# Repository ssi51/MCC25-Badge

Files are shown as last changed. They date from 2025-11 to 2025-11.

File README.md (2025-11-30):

# MCC25 Badge

  

## 🦇 Introduction

Welcome to the official repository for the **MCC 25' Badge**, a custom electronic conference badge based on the open-source [Hackbat Badge](https://hackaday.io/project/197688-hackbat-badge).

**📡 Repository Updates & Future Code**
This repository is the central hub for the MCC 25' Badge ecosystem. **It will be regularly updated with new firmware, games, and example codes.** We encourage you to "Watch" or "Star" this repository to get notified when new features are available to upload to your badge.

## ✨ Features

* **Wireless Connectivity**: Integrated 2.4GHz WiFi and Bluetooth 5.0 (LE) via the ESP32-C3.
* **Crisp Display**: 1.3-inch OLED screen for menus, games, and status updates.
* **Interactive Controls**: 6-button interface (D-Pad + A/B buttons) designed for gaming and navigation.
* **RGB Lighting**: 4x Addressable WS2812 LEDs for visual notifications and light shows.
* **Portable Power**: Runs on USB-C or AA batteries with dedicated power management.
* **Open Development**: Compatible with Arduino IDE and Espressif ESP-IDF.

## 🛠 Hardware Specifications

| Component | Specification |
| :--- | :--- |
| **Microcontroller** | Espressif **ESP32-C3** (RISC-V Single-core @ 160MHz) |
| **Display** | 1.3" OLED (SH110x / SSD1306 compatible) |
| **Connectivity** | WiFi 802.11b/g/n + Bluetooth LE 5.0 |
| **User Input** | 6 Push Buttons (Up, Down, Left, Right, A, B) |
| **LEDs** | 4 x WS2812B Addressable RGB LEDs |
| **Dimensions** | 100mm x 60mm |
| **Power Input** | USB Micro or 3x AA Battery Holder (Back mounted) |

## 🚀 Getting Started

### Prerequisites

To program the MCC25 Badge, you will need to install the necessary drivers and boards.

1.  **Install Arduino IDE**: Download from the [official website](https://www.arduino.cc/en/software).
2.  **Add ESP32 Board Manager**:
    * Go to `File` > `Preferences`.
    * Add the following URL to "Additional Board Manager URLs":
        `https://raw.githubusercontent.com/espressif/arduino-esp32/gh-pages/package_esp32_index.json`
    * Go to `Tools` > `Board` > `Boards Manager`, search for "ESP32", and install.

### Flashing Your First Sketch

1.  Select the board: `ESP32C3 Dev Module`.
2.  Ensure `USB CDC On Boot` is set to "Enable" if you are using the USB port for serial debugging.
3.  Connect your MCC25 Badge via USB-Micro.
4.  Select the correct Port under `Tools` > `Port`.
5.  Upload the example `Blink` or `DisplayTest` sketch from the `/examples` folder in this repo.

## 🔋 Powering the Badge

The MCC25 Badge can be powered in two ways:
1.  **USB Mode**: Connect a USB Micro cable for power and programming.
2.  **Battery Mode**: Insert 3x AA batteries into the rear holder. Use the physical slide switch to toggle battery power ON/OFF.
    * *Note: Ensure batteries are removed if you are modifying hardware components.*

## 📂 Repository Structure

* `/examples` - Source code, future updates, and example sketches.
* `/hardware` - PCB design files (Gerbers, Schematics).
* `/docs` - Datasheets and additional documentation.

## 🤝 Credits & Acknowledgments

* **Original Design**: Based on the **Hackbat Badge** by [Pablo on Hackaday.io](https://hackaday.io/project/197688-hackbat-badge).
* **MCU**: Powered by Espressif Systems.

## 📄 License

This project is open-source.

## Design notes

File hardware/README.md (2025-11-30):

# 🛠️ MCC25 Badge Hardware Design

This directory contains the Open Source Hardware (OSHW) design files for the **MCC25 Badge**. The PCB was designed using **KiCad** (Version 7.0+).

## 📂 File Descriptions

| File Name | Description |
| :--- | :--- |
| `mcc25_badge.kicad_pro` | Main KiCad Project file. Open this to start editing. |
| `mcc25_badge.kicad_sch` | **Schematic**: Shows how the ESP32-C3 connects to the OLED, LEDs, and buttons. |
| `mcc25_badge.kicad_pcb` | **PCB Layout**: The physical board routing, layers, and footprints. |
| `gerber.zip` | **Production Files**: The exact manufacturing files needed to order this board from a fab house. |

## 📐 Technical Specifications
* **Layers:** 2-Layer PCB
* **Dimensions:** 100mm x 60mm
* **Thickness:** 1.6mm (Standard)
* **Signal Voltage:** 3.3V Logic

## 🏭 How to Order This Board (Fabrication)

You don't need to install KiCad if you just want to manufacture the PCB.

1.  **Download the Gerbers**: Download the file `gerber.zip` from this folder.
2.  **Visit a Manufacturer**: Go to a PCB fabrication website (e.g., JLCPCB, PCBWay, AiPCBA).
3.  **Upload**: Drag and drop the `gerber.zip` file into their "Quote" tool.
4.  **Select Settings**: The defaults are usually fine, but ensure the following:
    * **Layers**: 2
    * **Thickness**: 1.6mm
    * **PCB Color**: Black (Matches the MCC aesthetic)
    * **Surface Finish**: HASL (Cheaper) or ENIG (Better for gold pads)
5.  **Order**: Add to cart and ship!

## ✏️ How to Modify the Design

If you want to change the logo, move buttons, or add sensors:

1.  Install **KiCad** (Free & Open Source) from [kicad.org](https://www.kicad.org/).
2.  Clone this repository to your computer.
3.  Double-click `mcc25_badge.kicad_pro` to open the project manager.
4.  Open the **Schematic Editor** to change connections or the **PCB Editor** to change the physical layout.

## ⚠️ Assembly Note
This board uses **SMD (Surface Mount Device)** components for the ESP32-C3 and LEDs.
* If ordering **PCB Assembly (PCBA)** services, you will need to provide them with the `BOM` (Bill of Materials) and `CPL` (Component Placement List).
* If assembling by hand, ensure you have a hot air station or a fine-tip soldering iron.

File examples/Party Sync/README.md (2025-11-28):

# 📡 Party Sync Mode

This firmware turns your MCC25 Badge into a connected "Party Device" using the **ESP-NOW** protocol. 

When any badge in the room presses the **A Button**, it takes control and forces *all* other badges nearby to change to the same LED color instantly.

### ✨ Features
* **Peer-to-Peer Networking**: Uses ESP-NOW (Connectionless WiFi) for ultra-low latency.
* **Broadcast Mode**: One message controls unlimited devices. No pairing required.
* **Dynamic Role Switching**: Any badge can become the "Leader" simply by pressing a button.
* **OLED Feedback**: Shows "LEADER" when you transmit, and "SYNCED!" when you receive a command.

### 🛠 Hardware Requirements
* MCC25 Badge (ESP32-C3)
* **Minimum 2 Badges** are required to see the effect!

### 📦 Library Dependencies
Ensure these are installed in Arduino IDE:
1.  **FastLED**
2.  **GyverOLED**

### 🚀 How to Test
1.  Upload this code to **Badge A**.
2.  Upload this code to **Badge B**.
3.  Power both on.
4.  Press **Button A** on Badge A -> Badge B will change color instantly.
5.  Press **Button A** on Badge B -> Badge A will change color instantly.

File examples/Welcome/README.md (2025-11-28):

# 🎆 Village Night Welcome

This is the initial "Hello World" firmware for the MCC25 Badge. It demonstrates the badge's multitasking capabilities by running a smooth graphics animation and LED control simultaneously without blocking.

### 📋 Features
* **OLED Display**: Scrolls the message *"Welcome to MCC 25' Village Night!"* from right to left using the `GyverOLED` engine.
* **RGB LEDs**: Cycles through Red, Green, Blue, and Off states every second using `FastLED`.
* **Non-Blocking Core**: Uses `millis()` for timing, ensuring the display animation remains fluid while LEDs update independently.

### 📦 Required Libraries
To compile this sketch, install these libraries via the Arduino Library Manager:
1.  **GyverOLED** (by AlexGyver)
2.  **FastLED** (by Daniel Garcia)

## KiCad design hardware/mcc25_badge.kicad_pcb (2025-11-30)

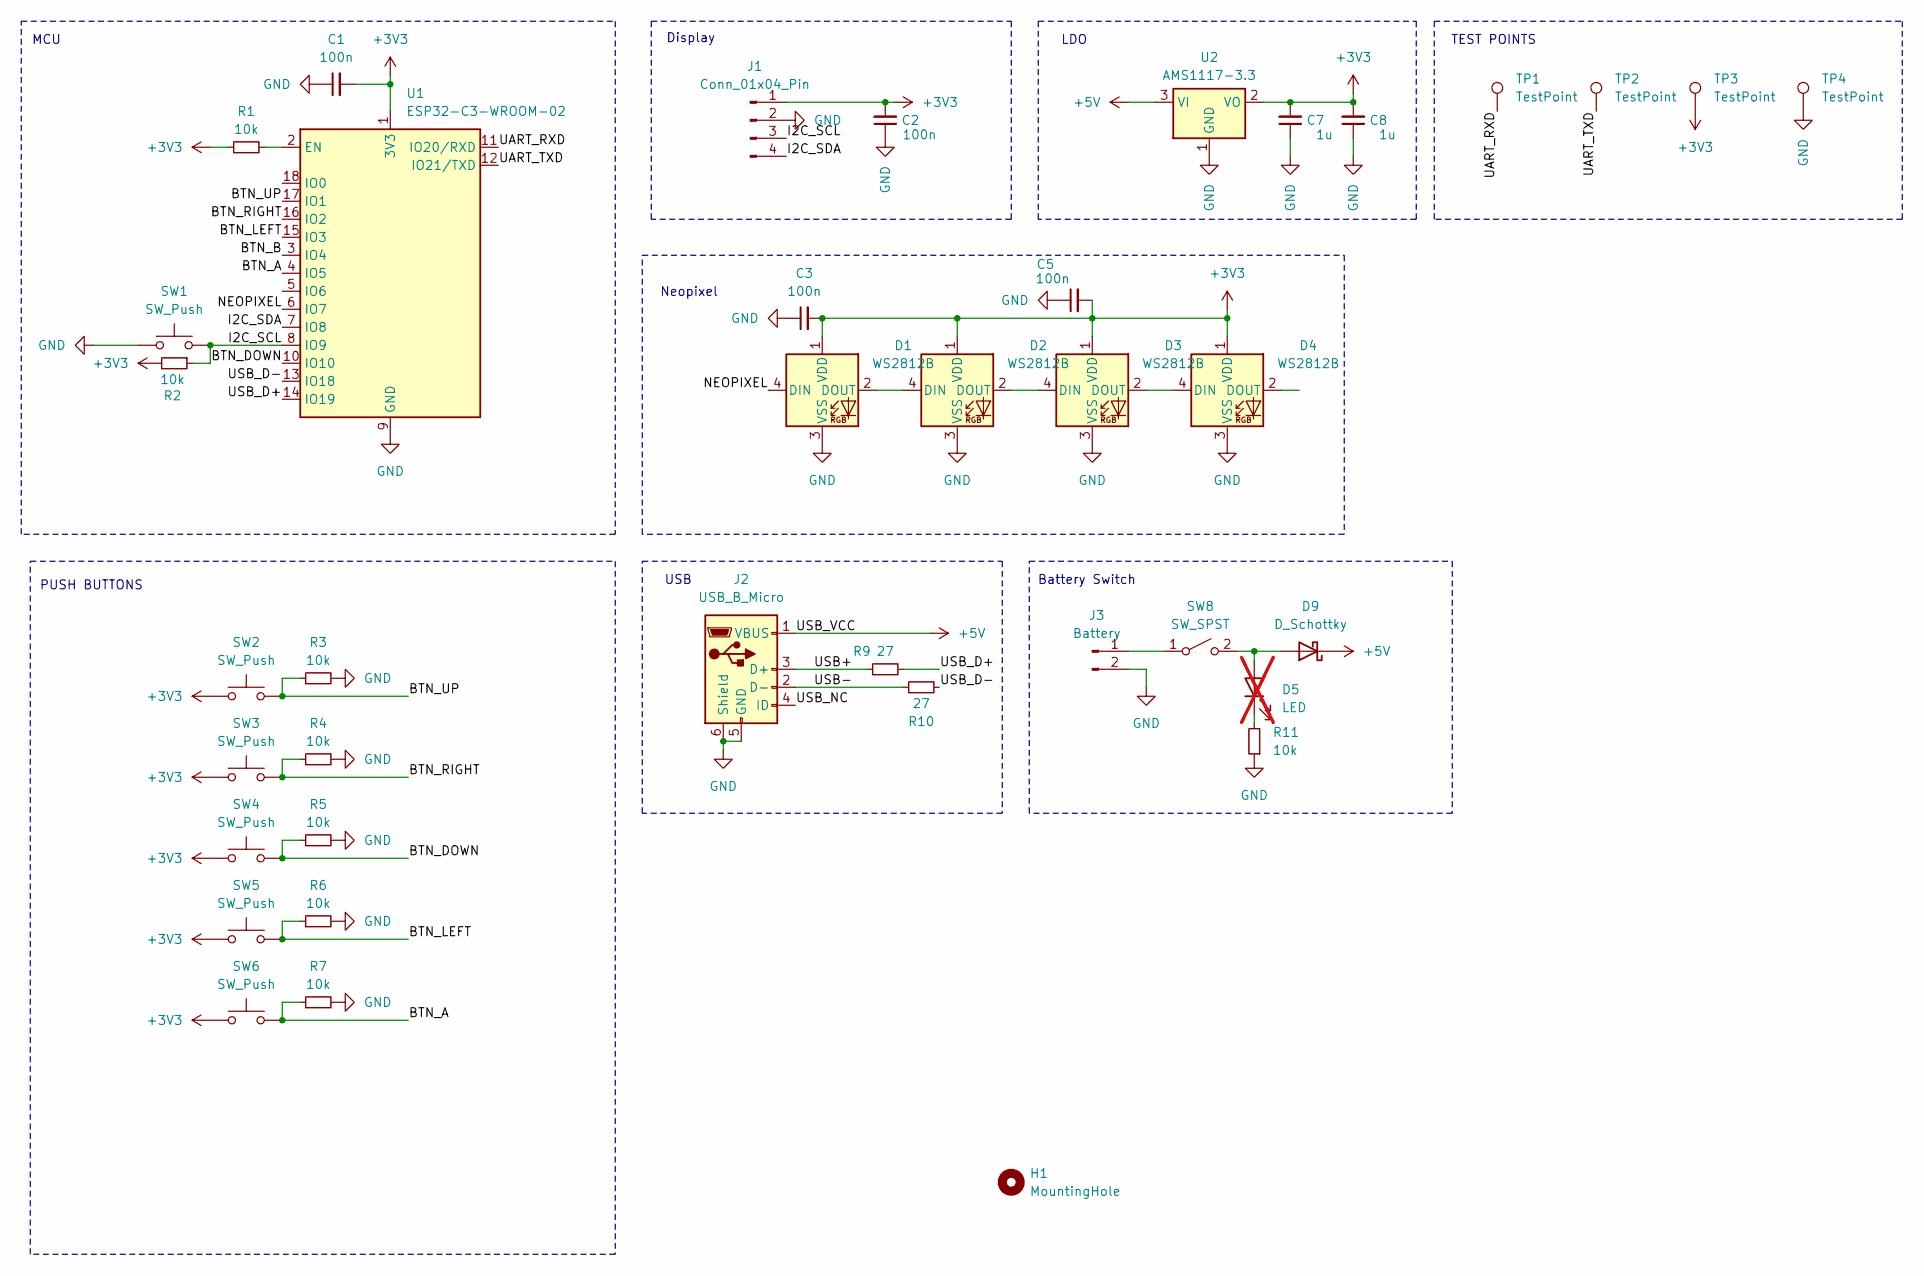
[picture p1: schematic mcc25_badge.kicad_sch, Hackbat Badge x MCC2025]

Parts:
C1, C2, C3, C5: 100n; C_0402_1005Metric
C7, C8: 1u; C_0805_2012Metric
D1, D2, D3, D4: WS2812B; LED_WS2812B_PLCC4_5.0x5.0mm_P3.2mm; JLCPCB Part # C2920042
D5: LED; LED_0805_2012Metric; not fitted
D9: D_Schottky; Nexperia_CFP3_SOD-123W; JLCPCB Part # C82544
H1: MountingHole; MountingHole_3.2mm_M3
J1: Conn_01x04_Pin; PinSocket_1x04_P2.54mm_Vertical
J2: USB_B_Micro; USB_Micro-B_Amphenol_10118193-0001LF_Horizontal; JLCPCB Part # C132562
J3: Battery; PinSocket_1x02_P2.54mm_Vertical_SMD_Pin1Left
R1, R2, R3, R4, R5, R6, R7, R11: 10k; R_0402_1005Metric
R9, R10: 27; R_0402_1005Metric
SW1: SW_Push; SW_Push_SPST_NO_Alps_SKRK; JLCPCB Part # C115357
SW2, SW3, SW4, SW5, SW6: SW_Push; SW_Push_1P1T_NO_6x6mm_H9.5mm; JLCPCB Part # C455109
SW8: SW_SPST; SW_SPDT_CK_JS102011SAQN; JLCPCB Part # C92658
TP1, TP2, TP3, TP4: TestPoint; TestPoint_Pad_D1.0mm
U1: ESP32-C3-WROOM-02; JLCPCB Part # C2934560
U2: AMS1117-3.3; SOT-223-3_TabPin2

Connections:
+3V3: C1.2, C2.2, C3.2, C5.2, C7.2, C8.2, D1.1 (VDD), D2.1 (VDD), D3.1 (VDD), D4.1 (VDD), J1.1, R1.1, R2.2, SW2.1, SW3.1, SW4.1, SW5.1, SW6.1, TP3.1, U1.1 (3V3), U2.2 (VO)
+5V: D9.1 (K), J2.1 (VBUS), U2.3 (VI)
/BTN_A: R7.1, SW6.2, U1.4 (IO5)
/BTN_B: U1.3 (IO4)
/BTN_DOWN: R5.1, SW4.2, U1.10 (IO10)
/BTN_LEFT: R6.1, SW5.2, U1.15 (IO3)
/BTN_RIGHT: R4.1, SW3.2, U1.16 (IO2)
/BTN_UP: R3.1, SW2.2, U1.17 (IO1)
/I2C_SCL: J1.3, R2.1, SW1.2, U1.8 (IO9)
/I2C_SDA: J1.4, U1.7 (IO8)
/NEOPIXEL: D1.4 (DIN), U1.6 (IO7)
/UART_RXD: TP1.1, U1.11 (IO20/RXD)
/UART_TXD: TP2.1, U1.12 (IO21/TXD)
/USB+: J2.3 (D+), R9.1
/USB-: J2.2 (D-), R10.1
/USB_D+: R9.2, U1.14 (IO19)
/USB_D-: R10.2, U1.13 (IO18)
/USB_NC: J2.4 (ID)
GND: C1.1, C2.1, C3.1, C5.1, C7.1, C8.1, D1.3 (VSS), D2.3 (VSS), D3.3 (VSS), D4.3 (VSS), J1.2, J2.5 (GND), J2.6 (Shield), J3.2, R3.2, R4.2, R5.2, R6.2, R7.2, R11.1, SW1.1, TP4.1, U1.9 (GND), U1.19 (GND), U2.1 (GND)
unnamed: D1.2 (DOUT), D2.4 (DIN)
unnamed: D2.2 (DOUT), D3.4 (DIN)
unnamed: D3.2 (DOUT), D4.4 (DIN)
unnamed: D5.2 (A), D9.2 (A), SW8.2 (B)
unnamed: D5.1 (K), R11.2
unnamed: J3.1, SW8.1 (A)
unnamed: R1.2, U1.2 (EN)

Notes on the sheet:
LDO
Display
USB
MCU
Neopixel
TEST POINTS
PUSH BUTTONS
Battery Switch

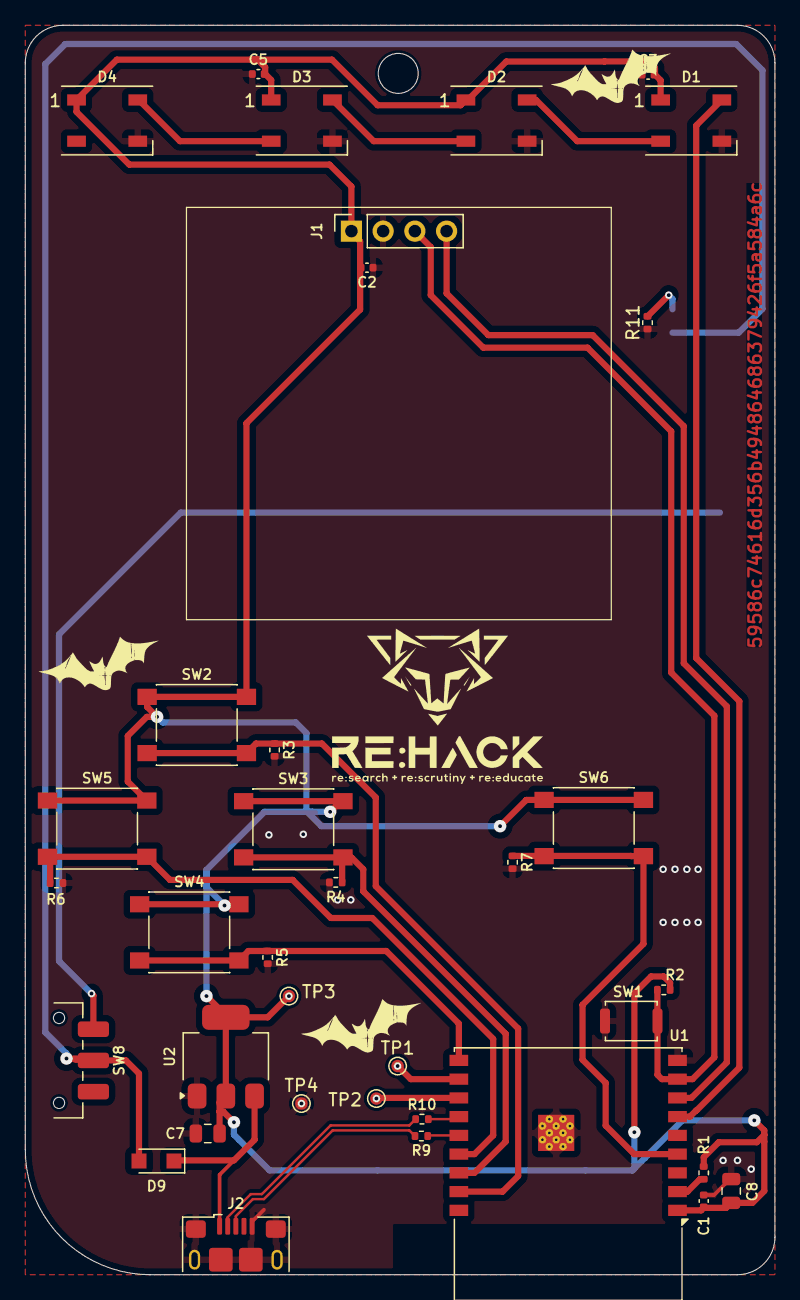
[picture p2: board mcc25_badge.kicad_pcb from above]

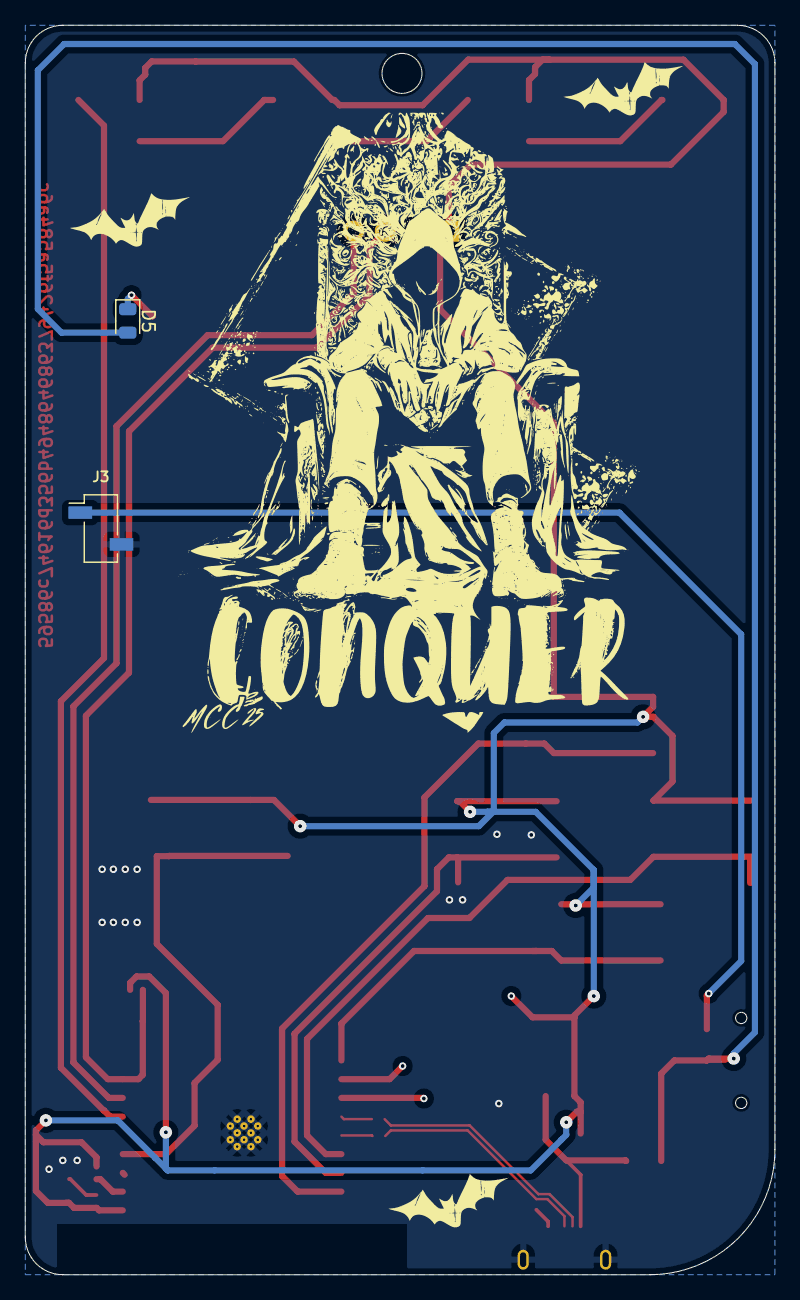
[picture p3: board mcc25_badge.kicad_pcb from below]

Board: 2 copper layers, 60.0 x 100.0 mm, 39 parts (2 on the bottom side), 24 nets.

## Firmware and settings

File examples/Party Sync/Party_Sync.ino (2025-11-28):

/*
 * Project: MCC25 Badge - Party Sync Mode (ESP-NOW)
 * Description: Peer-to-Peer LED synchronization.
 * * How to use:
 * - Load this code onto TWO or more badges.
 * - Press Button A on ANY badge.
 * - All badges in range will instantly change to the same color.
 */

#include <esp_now.h>
#include <WiFi.h>
#include <FastLED.h>
#include <GyverOLED.h>

// ================= HARDWARE CONFIG =================
#define BTN_A_PIN   10
#define LED_PIN     7
#define LED_COUNT   4

// ================= GLOBALS =================
CRGB leds[LED_COUNT];
GyverOLED<SSD1306_128x64> oled;

// Pre-defined colors to cycle through
CRGB colorList[] = {
  CRGB::Red, 
  CRGB::Blue, 
  CRGB::Green, 
  CRGB::Purple, 
  CRGB::Orange, 
  CRGB::Cyan,
  CRGB::Black // Off
};
int currentColorIndex = 0;
const int totalColors = 7;

// Structure of the data we send over the air
typedef struct struct_message {
  int colorIdx;
} struct_message;

struct_message myData;

// Broadcast address (sends to everyone)
uint8_t broadcastAddress[] = {0xFF, 0xFF, 0xFF, 0xFF, 0xFF, 0xFF};

// Info needed for ESP-NOW peer
esp_now_peer_info_t peerInfo;

// ================= CALLBACKS =================

// Function called when data is SENT
void OnDataSent(const wifi_tx_info_t *info, esp_now_send_status_t status) {
  // Optional: flash a tiny indicator pixel on OLED
  oled.setCursor(0, 7);
  oled.print(status == ESP_NOW_SEND_SUCCESS ? "TX: OK  " : "TX: Fail");
  oled.update();
}

// Function called when data is RECEIVED
void OnDataRecv(const esp_now_recv_info_t * info, const uint8_t *incomingData, int len) {
  memcpy(&myData, incomingData, sizeof(myData));
  
  // Update local color to match the party!
  currentColorIndex = myData.colorIdx;
  updateLEDs(currentColorIndex);
  
  // Update Display
  oled.clear();
  oled.setScale(2);
  oled.setCursor(10, 2);
  oled.print("PARTY");
  oled.setCursor(20, 4);
  oled.print("SYNC!");
  
  oled.setScale(1);
  oled.setCursor(0, 7);
  oled.print("RX from: ");
  // Print last byte of sender MAC for debug
  oled.print(info->src_addr[5], HEX); 
  oled.update();
}

// ================= HELPER FUNCTIONS =================

void updateLEDs(int idx) {
  fill_solid(leds, LED_COUNT, colorList[idx]);
  FastLED.show();
}

// ================= SETUP =================
void setup() {
  Serial.begin(115200);
  
  // Init Hardware
  pinMode(BTN_A_PIN, INPUT_PULLUP);
  FastLED.addLeds<WS2812, LED_PIN, GRB>(leds, LED_COUNT);
  FastLED.setBrightness(40); // Keep it low to save battery
  
  oled.init();
  oled.clear();
  oled.setScale(2);
  oled.setCursor(5, 3);
  oled.print("SYNC RDY");
  oled.update();

  // Init WiFi in Station Mode (Required for ESP-NOW)
  WiFi.mode(WIFI_STA);

  // Init ESP-NOW
  if (esp_now_init() != ESP_OK) {
    Serial.println("Error initializing ESP-NOW");
    oled.clear();
    oled.print("ESP-NOW FAIL");
    oled.update();
    return;
  }

  // Register Callbacks
  esp_now_register_send_cb(OnDataSent);
  esp_now_register_recv_cb(OnDataRecv);

  // Register Peer (The Broadcast Address)
  memcpy(peerInfo.peer_addr, broadcastAddress, 6);
  peerInfo.channel = 0;  
  peerInfo.encrypt = false;
  
  if (esp_now_add_peer(&peerInfo) != ESP_OK){
    Serial.println("Failed to add peer");
    return;
  }
}

// ================= LOOP =================
void loop() {
  // Check Button A
  if (digitalRead(BTN_A_PIN) == LOW) {
    delay(50); // Debounce
    if (digitalRead(BTN_A_PIN) == LOW) {
      
      // 1. Change YOUR color locally
      currentColorIndex++;
      if (currentColorIndex >= totalColors) currentColorIndex = 0;
      updateLEDs(currentColorIndex);

      // 2. Prepare data to send
      myData.colorIdx = currentColorIndex;

      // 3. Send to EVERYONE via ESP-NOW
      esp_err_t result = esp_now_send(broadcastAddress, (uint8_t *) &myData, sizeof(myData));
      
      // 4. Update Display
      oled.clear();
      oled.setScale(2);
      oled.setCursor(10, 2);
      oled.print("LEADER"); // You are the leader now
      oled.update();

      // Wait until button release so we don't spam commands
      while(digitalRead(BTN_A_PIN) == LOW); 
    }
  }
}

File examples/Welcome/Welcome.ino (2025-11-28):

#include <GyverOLED.h>
#include <FastLED.h>

/* WS2812 LED setting */
#define LED_COUNT           4
#define LED_PIN             7
CRGB leds[LED_COUNT];

/* OLED display (SSD1306 I2C, 128x64) */
GyverOLED<SSD1306_128x64> oled;

/* ----------- SCROLLING ENGINE VARIABLES ----------- */
const char* scrollTextStr = "Welcome to MCC 25' Village Night!";
int scrollX;              // current X position
int textWidth;            // total text width in pixels
unsigned long lastScrollUpdate = 0;
int scrollSpeed = 3;
uint8_t textScale = 2;

/* -------------- INITIALIZE SCROLL ENGINE ---------- */
void initScroll() {
  oled.setScale(textScale);
  textWidth = strlen(scrollTextStr) * 6 * textScale;
  scrollX = 128;  // start off right side
}

/* -------------- NON-BLOCKING SCROLLER -------------- */
void scrollEngine() {
  if (millis() - lastScrollUpdate >= scrollSpeed) {
    lastScrollUpdate = millis();

    oled.clear();
    oled.setScale(textScale);
    oled.setCursor(scrollX, 2);
    oled.print(scrollTextStr);
    oled.update();

    scrollX--;  // move left

    if (scrollX < -textWidth) {
      scrollX = 128; // restart from right
    }
  }
}


/* -------------------------- SETUP -------------------------- */
void setup()
{
  /* Initialize LEDs */
  FastLED.addLeds<WS2812, LED_PIN, GRB>(leds, LED_COUNT);
  FastLED.setBrightness(50);

  /* OLED init */
  oled.init();
  oled.clear();

  initScroll();   // start scrolling engine
}


/* --------------------------- LOOP --------------------------- */
void loop()
{
  scrollEngine();   // scroll text smoothly (non-blocking)
  rgb_update();     // LED animations still work normally
}


/* ------------------------ LED EFFECTS ------------------------ */
void rgb_update()
{
  static uint8_t state = 0;
  static unsigned long last = 0;

  if (millis() - last < 1000) return;  // update LEDs every 1 sec
  last = millis();

  switch (state) {
    case 0: fill_solid(leds, LED_COUNT, CRGB(15,0,0)); break;
    case 1: fill_solid(leds, LED_COUNT, CRGB(0,15,0)); break;
    case 2: fill_solid(leds, LED_COUNT, CRGB(0,0,15)); break;
    case 3: fill_solid(leds, LED_COUNT, CRGB(0,0,0)); break;
  }

  FastLED.show();
  state = (state + 1) % 4;
}

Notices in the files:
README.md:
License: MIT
